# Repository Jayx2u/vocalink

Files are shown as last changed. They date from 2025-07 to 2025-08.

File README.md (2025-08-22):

# VOCALINK
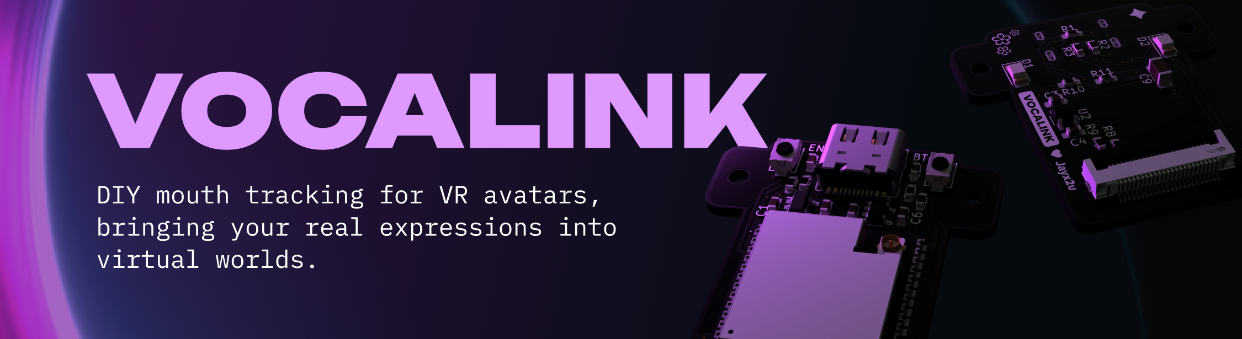
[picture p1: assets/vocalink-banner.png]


VOCALINK is a DIY mouth tracking solution built on [Project Babble](https://github.com/Project-Babble/ProjectBabble) that brings natural facial expressions to your VR avatar. 

I wanted deeper immersion in social VR platforms, but got tired of my avatar's lifeless stare while the rest of my body moved freely through virtual worlds. VOCALINK solves this by capturing real-time mouth and jaw movements with an OV2640 camera and machine learning, translating every smile, word, and expression into authentic avatar animations that finally make virtual conversations feel genuinely human.

> [!CAUTION]
> Please exercise extreme caution when messing around with IR emitters. Whilst the eyes are not directly exposed to the IR emitters, they are in close vicinity with each other. Please make sure you know what you are doing when assembling the IR emitters. I am not responsible for any damages you cause when using the designs provided in this project. 

## Hardware Design
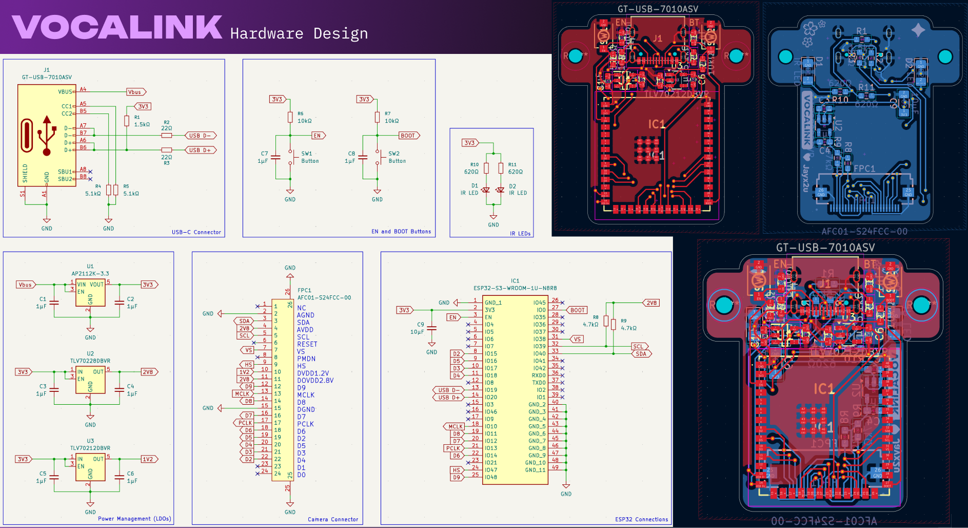
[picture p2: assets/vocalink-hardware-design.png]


## Mounting Design
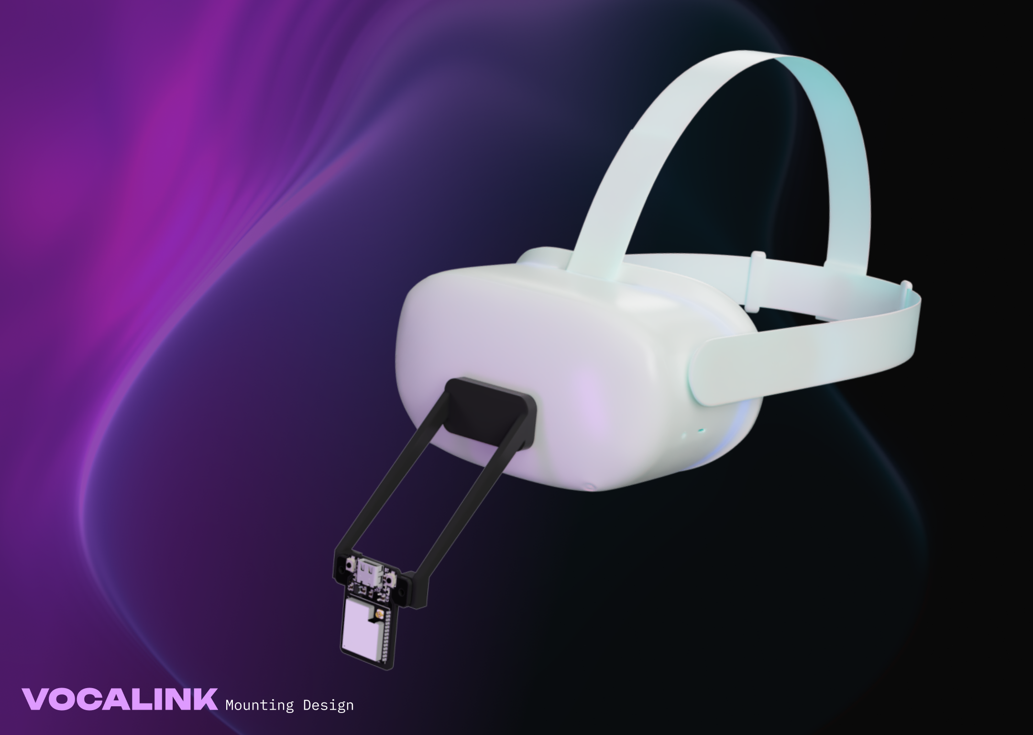
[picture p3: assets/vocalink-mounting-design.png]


## Showcase




## Video Demo
https://youtu.be/pk8RPQfYxws

## Bill Of Materials
<details>
<summary>Click to expand/collapse</summary>

| Part # | LCSC # | Order Quantity | Unit Price (USD) | Ext. Price (USD) | Link |
|---|---|---|---|---|---|
| UMK107AB7105KA-T | C105174  | 50 | 0.0181 | 0.91 | https://lcsc.com/product-detail/multilayer-ceramic-capacitors-mlcc-smd-smt_taiyo-yuden-umk107ab7105ka-t_C105174.html |
| CL31B106KBHNNNE | C89632 | 10 | 0.0629 | 0.63 | https://lcsc.com/product-detail/multilayer-ceramic-capacitors-mlcc-smd-smt_samsung-electro-mechanics-cl31b106kbhnnne_C89632.html |
| XL-3216HIRC-850 | C965891  | 20 | 0.0283 | 0.57 | https://lcsc.com/product-detail/infrared-led-emitters_xinglight-xl-3216hirc-850_C965891.html |
| AFC01-S24FCC-00 | C262276  | 5 | 0.1124 | 0.56 | https://lcsc.com/product-detail/ffc-fpc-flat-flexible-connector-assemblies_jushuo-afc01-s24fcc-00_C262276.html |
| ESP32-S3-WROOM-1U-N8R8 | C2980300 | 1 | 5.5182 | 5.52 | https://lcsc.com/product-detail/wifi-modules_espressif-esp32-s3-wroom-1u-n8r8_C2980300.html |
| GT-USB-7010ASV | C2988369 | 5 | 0.0805 | 0.40 | https://lcsc.com/product-detail/usb-connectors_g-switch-gt-usb-7010asv_C2988369.html |
| 0603WAF1501T5E | C22843 | 100 | 0.0011 | 0.11 | https://lcsc.com/product-detail/chip-resistor-surface-mount_uni-royal-0603waf1501t5e_C22843.html |
| RC0603FR-0722RL | C107701  | 100 | 0.0012 | 0.12 | https://lcsc.com/product-detail/chip-resistor-surface-mount_yageo-rc0603fr-0722rl_C107701.html |
| FRC0603F5101TS | C2907044 | 100 | 0.0010 | 0.10 | https://lcsc.com/product-detail/chip-resistor-surface-mount_fojan-frc0603f5101ts_C2907044.html |
| RC0603FR-0710KL | C98220 | 100 | 0.0011 | 0.11 | https://lcsc.com/product-detail/chip-resistor-surface-mount_yageo-rc0603fr-0710kl_C98220.html |
| RC0603FR-074K7L | C99782 | 100 | 0.0011 | 0.11 | https://lcsc.com/product-detail/chip-resistor-surface-mount_yageo-rc0603fr-074k7l_C99782.html |
| RC0603FR-07620RL | C137695  | 100 | 0.0012 | 0.12 | https://lcsc.com/product-detail/chip-resistor-surface-mount_yageo-rc0603fr-07620rl_C137695.html |
| TS-1088-AR02016 | C720477  | 10 | 0.0412 | 0.41 | https://lcsc.com/product-detail/tactile-switches_xunpu-ts-1088-ar02016_C720477.html |
| AP2112K-3.3TRG1 | C51118 | 5 | 0.1091 | 0.55 | https://lcsc.com/product-detail/voltage-regulators-linear-low-drop-out-ldo-regulators_diodes-ap2112k-3-3trg1_C51118.html |
| TLV70228DBVR | C183080  | 5 | 0.1024 | 0.51 | https://lcsc.com/product-detail/voltage-regulators-linear-low-drop-out-ldo-regulators_ti-tlv70228dbvr_C183080.html |
| TLV70212DBVR | C81462 | 5 | 0.1154 | 0.58 | https://lcsc.com/product-detail/voltage-regulators-linear-low-drop-out-ldo-regulators_ti-tlv70212dbvr_C81462.html |
| OV2640 Night Vision | N/A | 1 | 1 | 0 | https://www.aliexpress.com/item/1005003040149873.html |
| | | | | | |
| LCSC Components | | US$15.92 | | | |
| LCSC Shipping | | US$9.34 | | | |
| Economic PCBA - Front Layer | A$50.54  | ~US$33 | | | |
| JLCPCB Shipping | A$16.86  | ~US$11 | | | |
</details>

**Total: US$70.26**

## Acknowledgments
- [Project Babble](https://github.com/Project-Babble/ProjectBabble) - Firmware for mouth tracking and hardware selection guide.
- [Oculus Quest 2 3D Model](https://skfb.ly/otI9p) - by Nosakhae is licensed under [Creative Commons Attribution](http://creativecommons.org/licenses/by/4.0/).

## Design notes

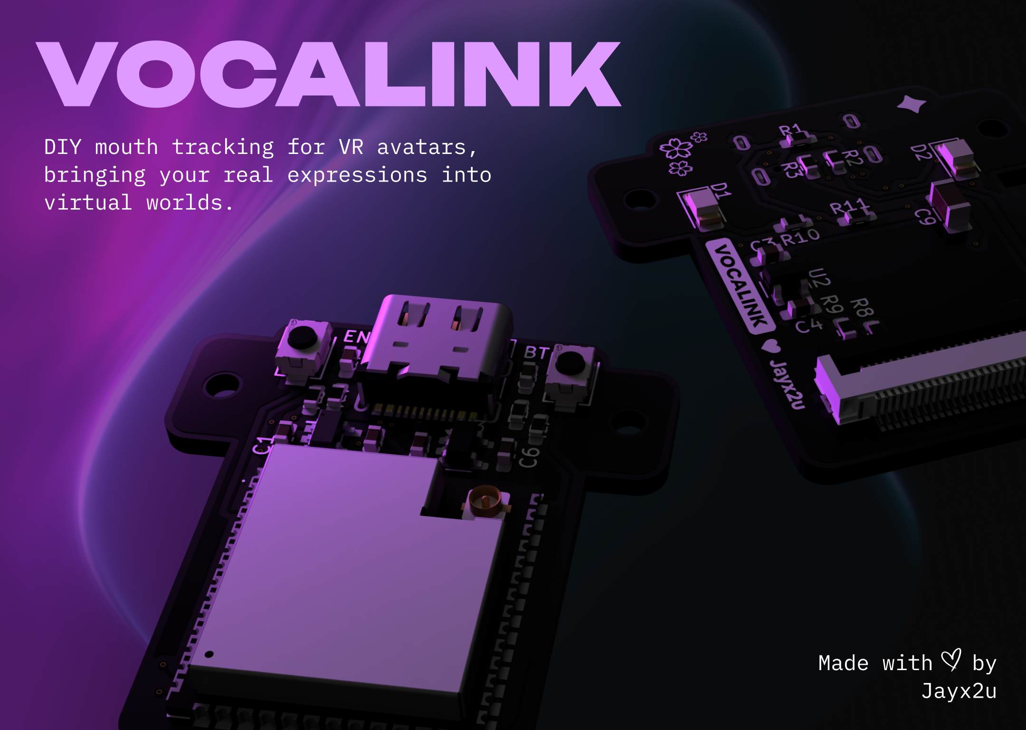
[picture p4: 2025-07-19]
assets/vocalink-thumbnail.png

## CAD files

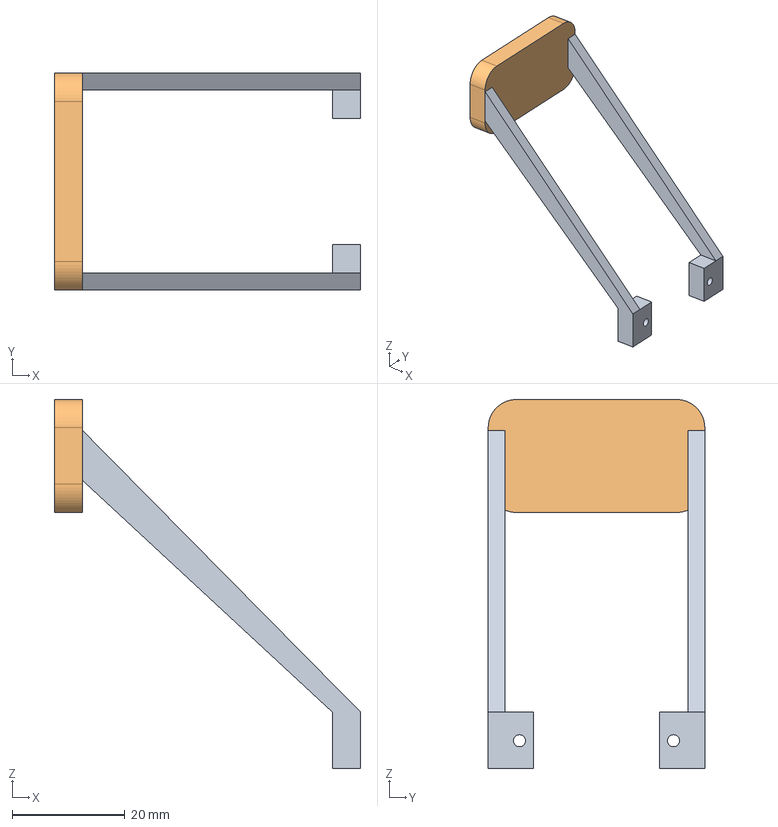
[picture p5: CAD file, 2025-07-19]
mount/vocalink-mount.step
54.2 x 38.4 x 65.3 mm

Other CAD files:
mount/vocalink-mount.f3d

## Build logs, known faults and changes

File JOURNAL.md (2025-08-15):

---
title: "VocaLink"
author: "Jayx2u"
description: "DIY mouth tracking for VR avatars, bringing your real expressions into virtual worlds. Built on Project Babble."
created_at: "2025-06-26"
---
**Total Design Hours: 35h**
**Total Build Hours: 10h**

# 2025-07-09 - More expressions!!!!!
I play VRChat... 🗑️😱🤯

I know I know, very crazy social platform but once you find the right friend group, it's a great way to socialise. I want to express myself more in VR. I've already got full body tracking ✅, but facial expression ❌. Tracking the eye and face, lets see how other peeps have done it.

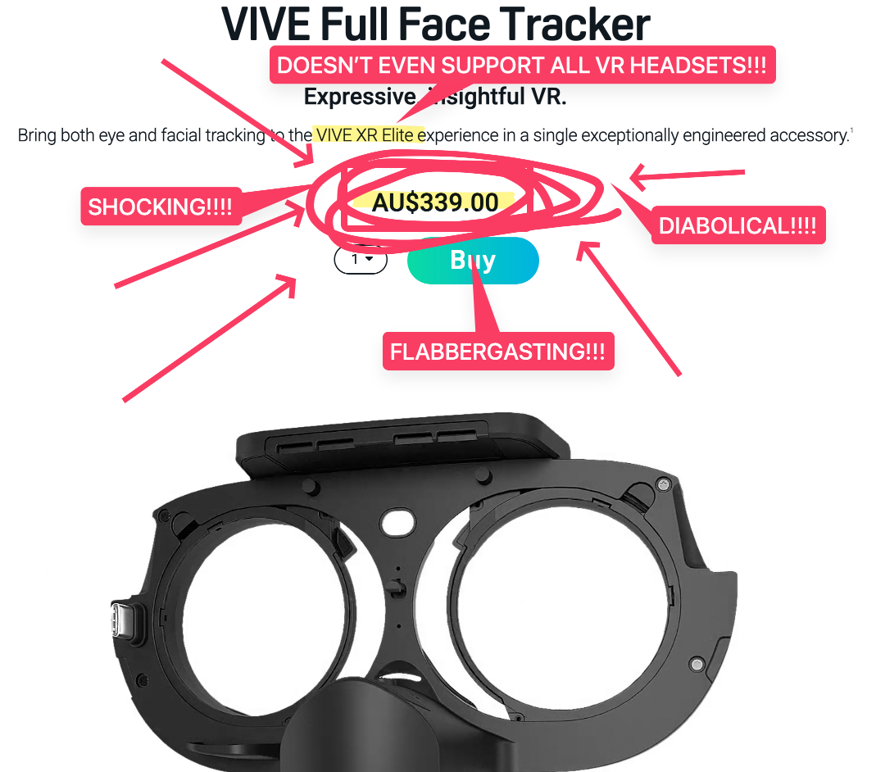
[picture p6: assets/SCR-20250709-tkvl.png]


Yeah no thank you 🙂‍↔️. So it's time to DIY it! I decided that I won't be making an eye tracker and will just focus on the mouth tracking aspect. Why? Because eye trackers need IR LEDs and I would not like to [risk getting blindness](https://docs.eyetrackvr.dev/getting_started/led_safety). 

Some research led to [Babble](https://babble.diy/), a "Source First" mouth tracking solution. They provide the firmware and machine learning model whilst also providing a guide showing how to use a Xiao ESP32 Sense with an OV2640 and some IR LEDs... but that sounds too easy so I'm going to use a bare ESP32 chip and make it all on one PCB.

*Time Spent: 1 hour*

# 2025-07-10 - Schematic creation
Today is the day before I travel to Undercity so it's time to speedrun the schematic. I decided to go with the `ESP32-S3-WROOM-1U-N8R8` as the brains since it has in-built RAM and it uses an external antenna. The camera will be the `OV2640` as it is the one recommended by Babble. It has a high FOV and is an IR camera. The IR LEDs brightening up my mouth will be the `XL-3216HIRC-850`. They are unfocused 3.3V 850mn IR emitters. This in combination with 620ohm resistors should result it in having around 9% of the safe limit of IR exposure to the eyes. Even though they are not directly pointed to the eyes like eye trackers, they will be extremely close to my face so I would not like to take any risks. The connector will be USB-C obviously.

Let's talk about power management now. Very not fun... power go through USB-C port, supplying the standard 5V Vbus, which is then directed to the `AP2112K-3.3`, an LDO regulator which steps down the voltage from 5V to 3.3V. For the specific voltage requirements of 2.8V and 1.2V, I have another two LDOs, `TLV70228DBVR` for 2.8V and `TLV70212DBVR` for 1.2V. They each have an input and output capacitor to ensure voltage stability and filtering out noise.  

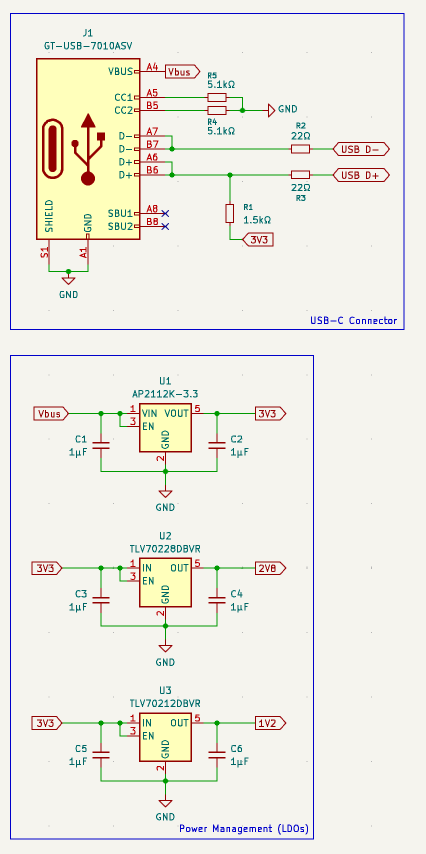
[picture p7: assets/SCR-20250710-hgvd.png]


Now some stuff for the microcontroller: The USB lines are connected to the ESP32's internal USB peripheral magical thingys. Then I have SW1 and SW2. One for `ENABLE (EN)`, acting as the reset button and then one for `BOOT`, for... you know... booting the device.

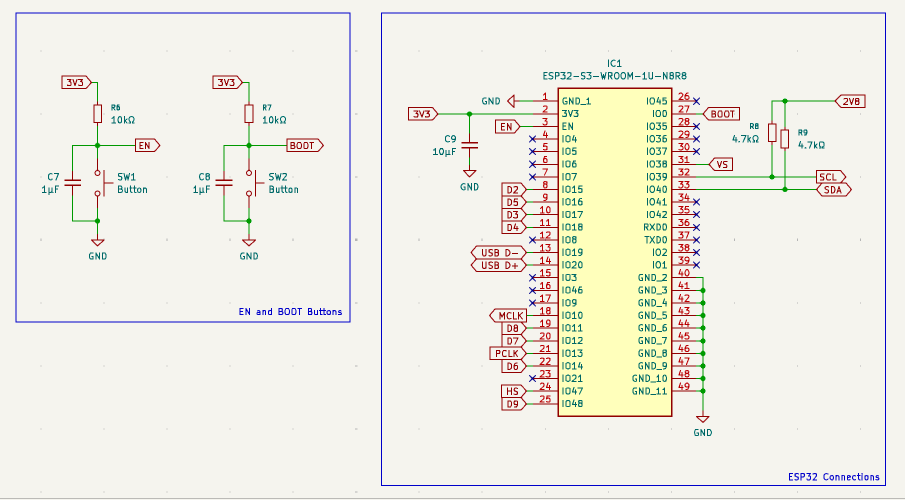
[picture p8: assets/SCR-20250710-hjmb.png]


Next is the camera and lighting. To connect the camera to the microcontroller, I added a 24-pin FPC connector. This connector breaks out all necessary signals: the 2.8V and 1.2V power rails generated by our LDOs, I2C communication lines (SCL and SDA) for camera configuration, and a parallel 8-bit data bus (D0-D7) for image data transfer. Clocking signals like PCLK, MCLK, HS, and VS are also routed from the ESP32 to this connector to synchronize data capture. To help the camera see and brighten up the area underneath the VR headset (which is where the camera will be located), two IR LEDs will be placed.

And with that, here is the schematic in all its glory:
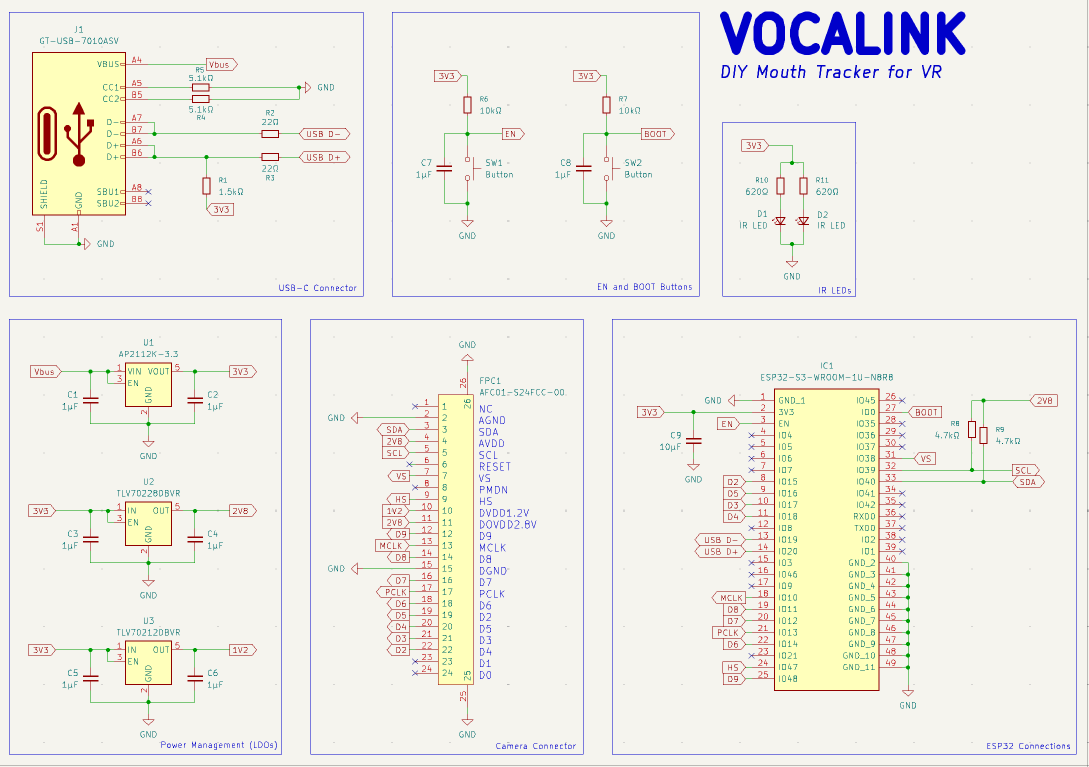
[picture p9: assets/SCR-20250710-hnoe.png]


*Time Spent: 13h*

# 2025-07-16 - Post-Undercity depression

Hi. It's me. You should go on a side-quest and see what my team made at Undercity! Made it into the Top 10: [Blind Defusal](https://github.com/Jayx2u/blind-defusal). Currently at a 22hr layover so it's time to speedrun the PCB!!!111!!11!! ._.

On the front layer, we got the "control deck." Got the big brain ESP32 with the USC-C connector at the top. Positioned very nicely so the cable can be firmly attached with the mount and cleanly around the VR headset. Go the two button there also for easy access. 

The back layer is the eyes of the deck. I got mainly the very big 24-pin FPC connector here and the IR LEDs on the sides for ample lighting. Hopefully the ground planes help with heat dissipation???

The main time waster here is going to be making the PCB footprint as small as possible. PCB tracing is art, and this is definitely some fine art. 🤭

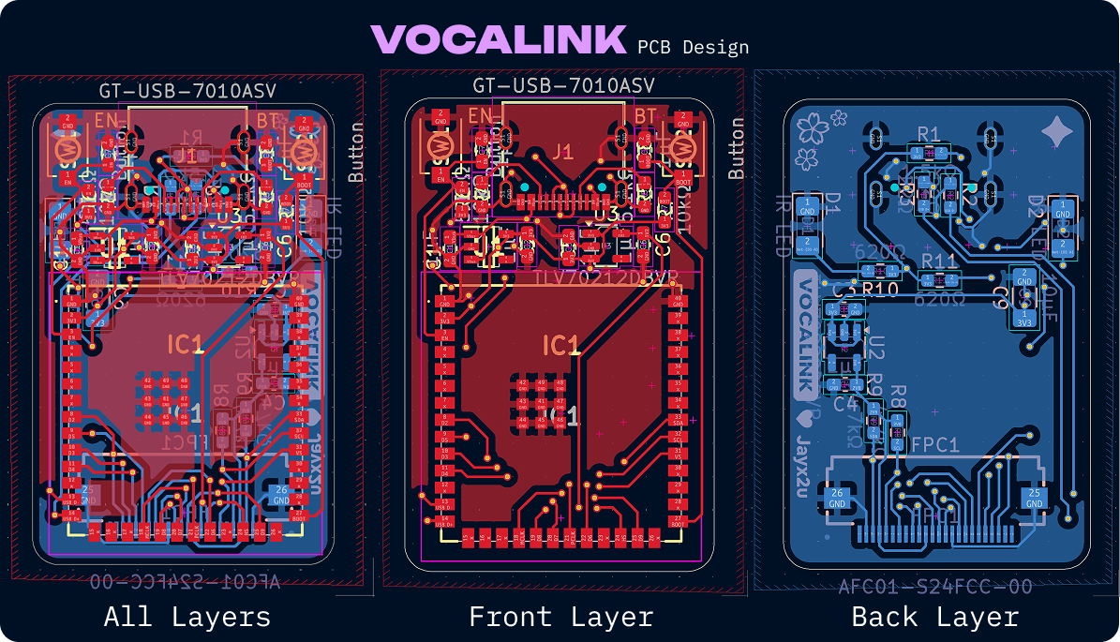
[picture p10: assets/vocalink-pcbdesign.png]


Beautiful isn't it. Brings solder fumes to my eyes 🥹. Anyways I decided to hit the sack after this.

*Time Spent: 16h*

# 2025-07-19 - Final revisions to PCB and speedrunning CAD

After a day of sleeping in down under, it is time to do the CAD. Here is a rough idea of how I want to mount it.

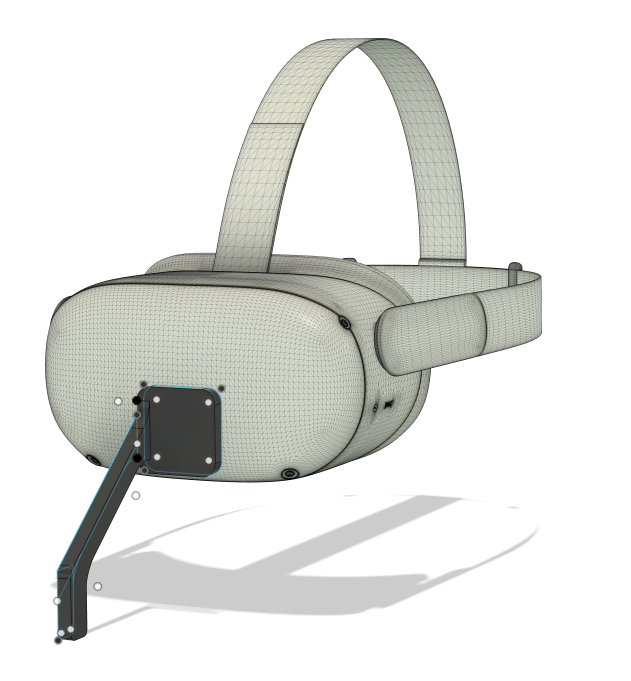
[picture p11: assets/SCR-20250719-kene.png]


The Quest 2 model was from [Nosakhae](https://sketchfab.com/3d-models/oculus-quest-2-c6a1c2623d224a1bbb81a38915f7e898). The plan is to use some sticky film to just stick it to the front of the headset. This shouldn't be an issue since everything is lightweight. Then it hits me... how do I mount the PCB to the actual mount?? Back to the PCB drawing board:

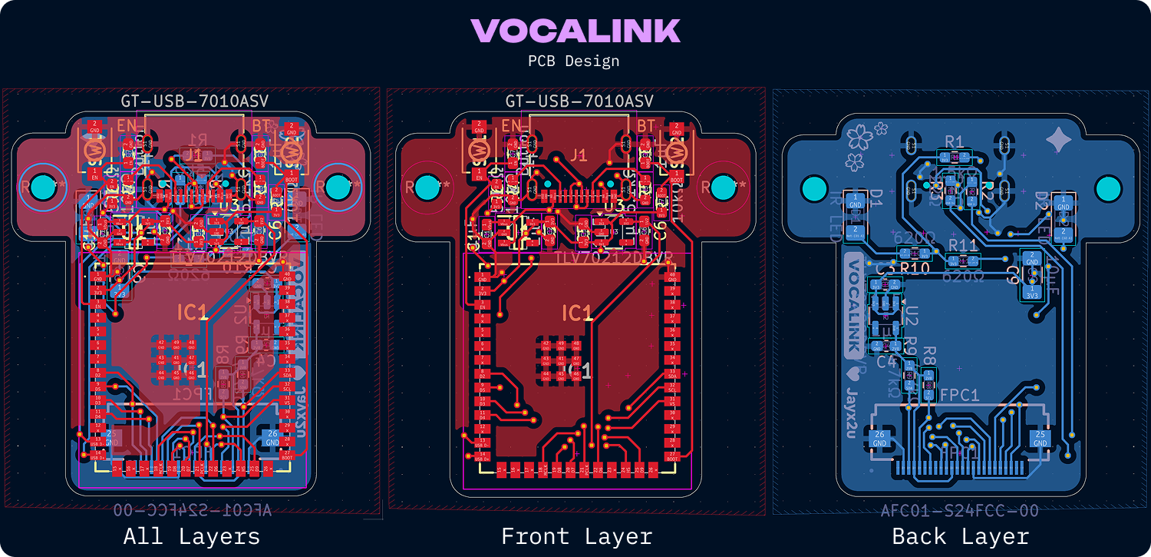
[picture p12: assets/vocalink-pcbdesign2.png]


Annnnnd now it has ears. Some off camera grinding later and here we have the mount design. Looks... meh, 3D CAD designing is not my forte...

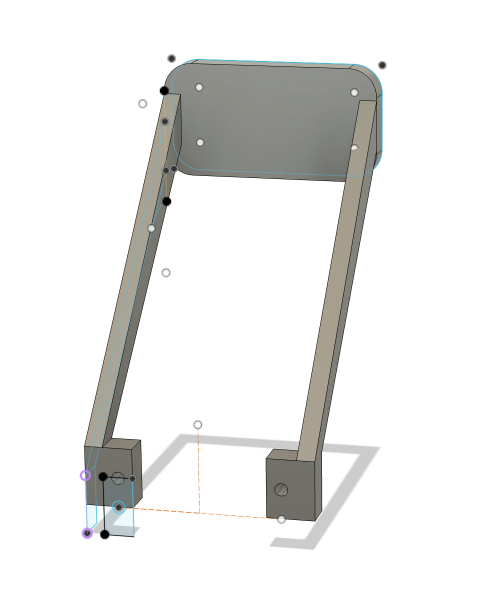
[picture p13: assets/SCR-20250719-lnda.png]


*Time Spent: 1h*

# 2025-07-19 - Beautifying the project and prepping for submission
Whilst not hardware or CAD designing, I feel like beautifying a project really gives everything a finished touch. First was the renders of the PCBs. I exported the STEP files of the PCB from KiCAD, changed the materials in Fusion 360 and here is how I rendered it:

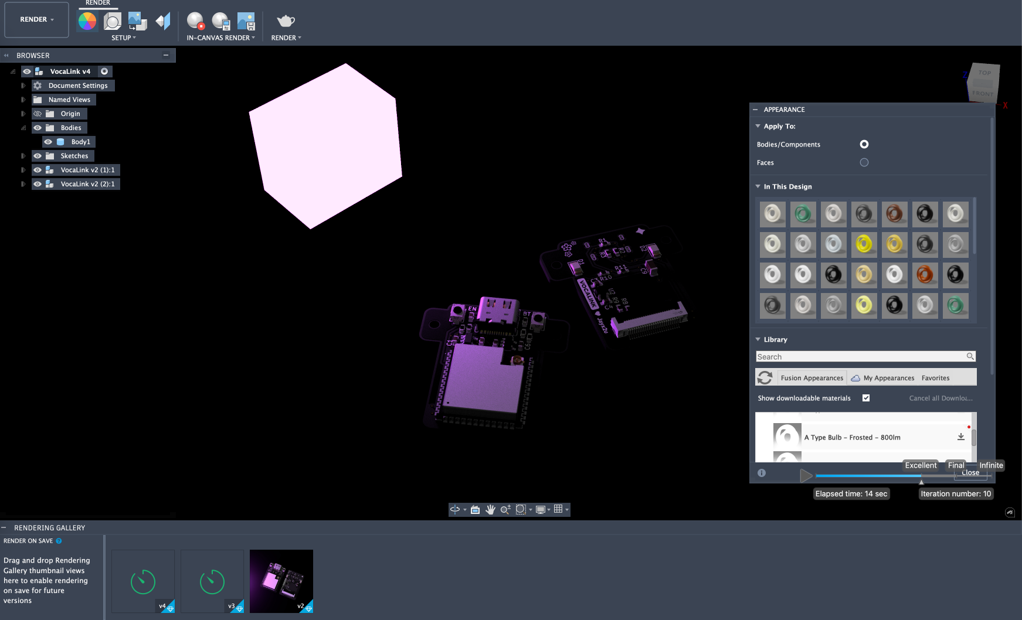
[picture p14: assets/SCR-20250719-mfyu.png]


After that, it's time to use Figma to make the finals designs. You can see the end results in the [README](/README.md).

Next is BOM and production files. I made the BOM using [LCSC's BOM Tool](https://lcsc.com/bom) then simplified it which resulted in this [BOM](/BILL-OF-MATERIALS.csv). For the PCBA production files, I used the [Fabrication-Toolkit](https://github.com/bennymeg/Fabrication-Toolkit) KiCAD library which gave me all the files I need for JLCPCB's PCBA service.

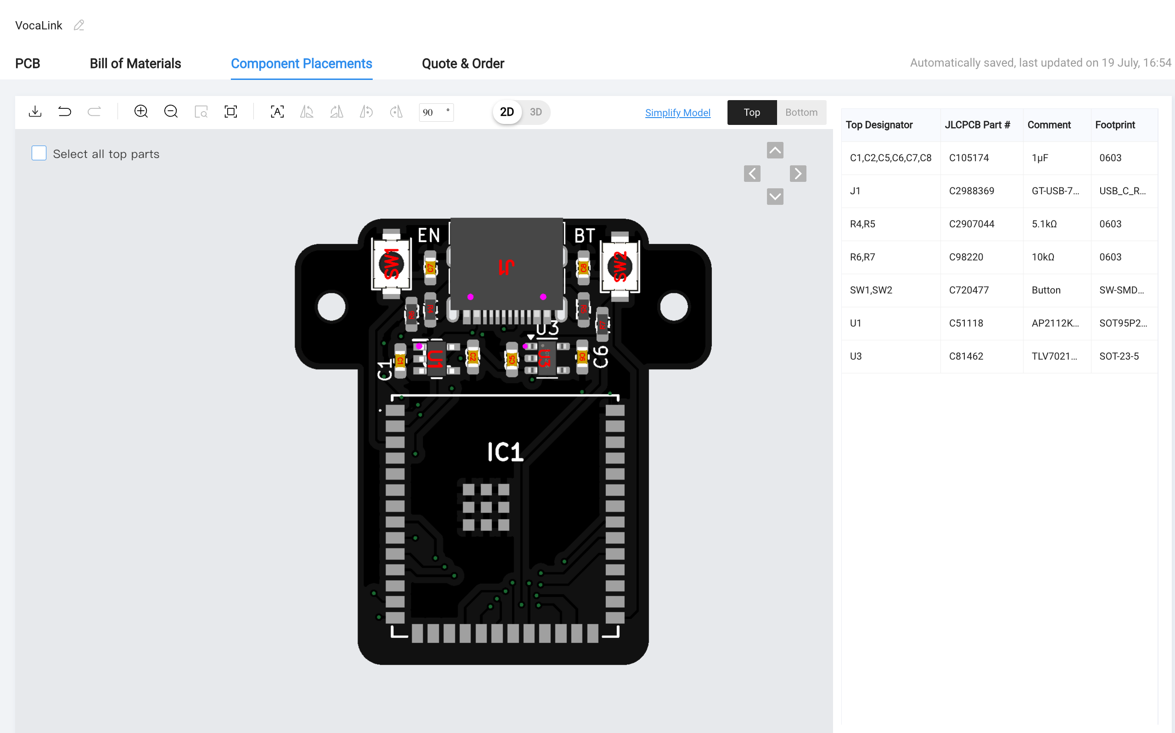
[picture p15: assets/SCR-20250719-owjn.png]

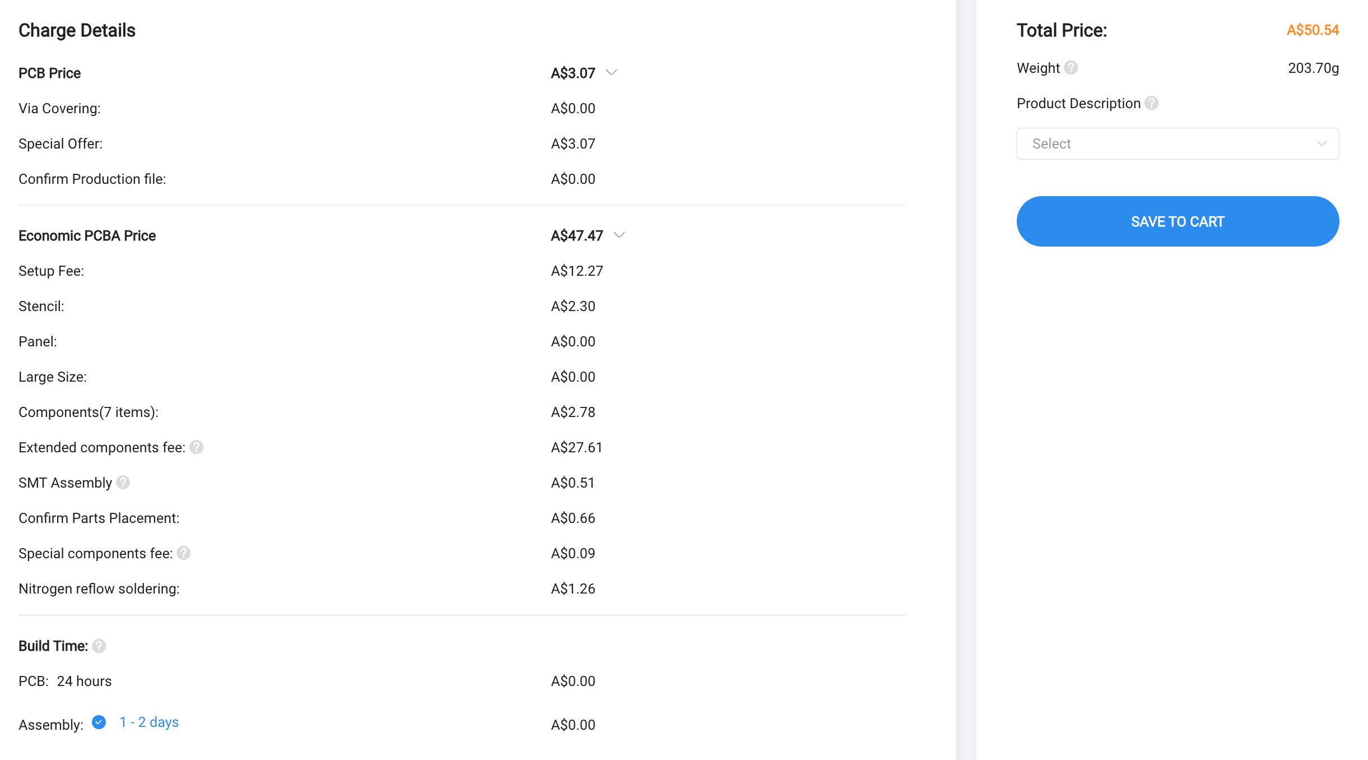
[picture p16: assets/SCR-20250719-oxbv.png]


With this, I updated my BOM and the project is ready to be submitted! 🎉

*Time Spent: 4h*

# 2025-08-09 - Lock in for soldering
It is the day. With a hot air reflow station and a hot plate borrowed from the school, solder paste bought from a local store and a friend to help me out, it's time to solder everything...

Photo of the setup:



The soldering of the esp was fine, we just pre pasted and cooked the pcb until it melted.



With the back of the pcb, we just pre applied the paste then held the component with tweezers and blasted hot air onto it. Worked pretty well.

All was good until we got to the FPC connector. It was so hard to solder and not get any of the pads to bridge.



In the end... we grimaced the pads.



But all is good! We have a second pcb to attempt on. When soldering the esp on, we managed to delid it..



After that fiasco, we tried the FPC connector first, as you can see, it was prettyyyy hard



After several attempts, we got this absolute abomination



But everything seems to be fine so we soldered everything else down and started flashing it:



And that is the build complete! First time hot air reflow soldering... it was quite the experience

*Time Spent: 8h*

# 2025-08-14 - Finishing up and demoing

I know it is the day of the due date... we don't talk about that. I got my mount 3D printed by a friend. I attached it to my headset and this is what the finished product looks like:





Installed Project Babble (ML model for mouth tracking) and VRCFT (software for making face tracking work in VRChat) which resulted in this demo video: https://youtu.be/pk8RPQfYxws

*Time Spent: 2h*

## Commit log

2025-07-16 Update journal with schematic entries
2025-07-16 journal: Update with current progress
2025-07-19 mount: Add CAD design and STEP file
    [vocalink-mount.f3d, vocalink-mount.step]
2025-07-19 assets: Update pcb design
2025-07-19 Add BOM
    [vocalink-bom.csv]
2025-07-19 Rename BOM
    [BILL-OF-MATERIALS.csv]
2025-07-19 assets: Add mounting design
2025-07-19 bom: Add PCBA service cost
    [BILL-OF-MATERIALS.csv]
2025-07-19 bom: Update PCBA price
    [BILL-OF-MATERIALS.csv]
2025-07-19 bom: Add links
    [BILL-OF-MATERIALS.csv]
2025-07-19 bom: Fix error
    [BILL-OF-MATERIALS.csv]
2025-07-19 readme: Add disclaimer and BOM
2025-07-19 pcb: Add kicad project and production files
    [bom.csv, designators.csv, positions.csv]
2025-07-19 assets: Update mounting design image
2025-07-19 bom: Add shipping costs
    [BILL-OF-MATERIALS.csv]
2025-07-19 bom: Update with correct cost
    [BILL-OF-MATERIALS.csv]
2025-07-19 bom: Add camera cost (somehow forgot the main sensor)
    [BILL-OF-MATERIALS.csv]
